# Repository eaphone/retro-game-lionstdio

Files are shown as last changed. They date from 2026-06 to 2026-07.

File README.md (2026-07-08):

# retro-game-lionstdio
a retro games console 

# Brief introduction:
## firmware based on [retro-go](https://github.com/eaphone/retro-go) integrated gba, dos simulator. add wired coplay, video player.
GBA, [Dos simulator](assets/dos-effect.gif) and video player.<br>
 
| win95 runing on esp32 | LEGEND runing on esp32s3 | video player |
| ---- | ---- | ---- |
|  |  | Videoplayer |

## hw use ili9342 drive 2.4 inch half transparent tft display, powered by esp32s3/p4
display without backlight, under sunshine effect \


# 3d print case without screw
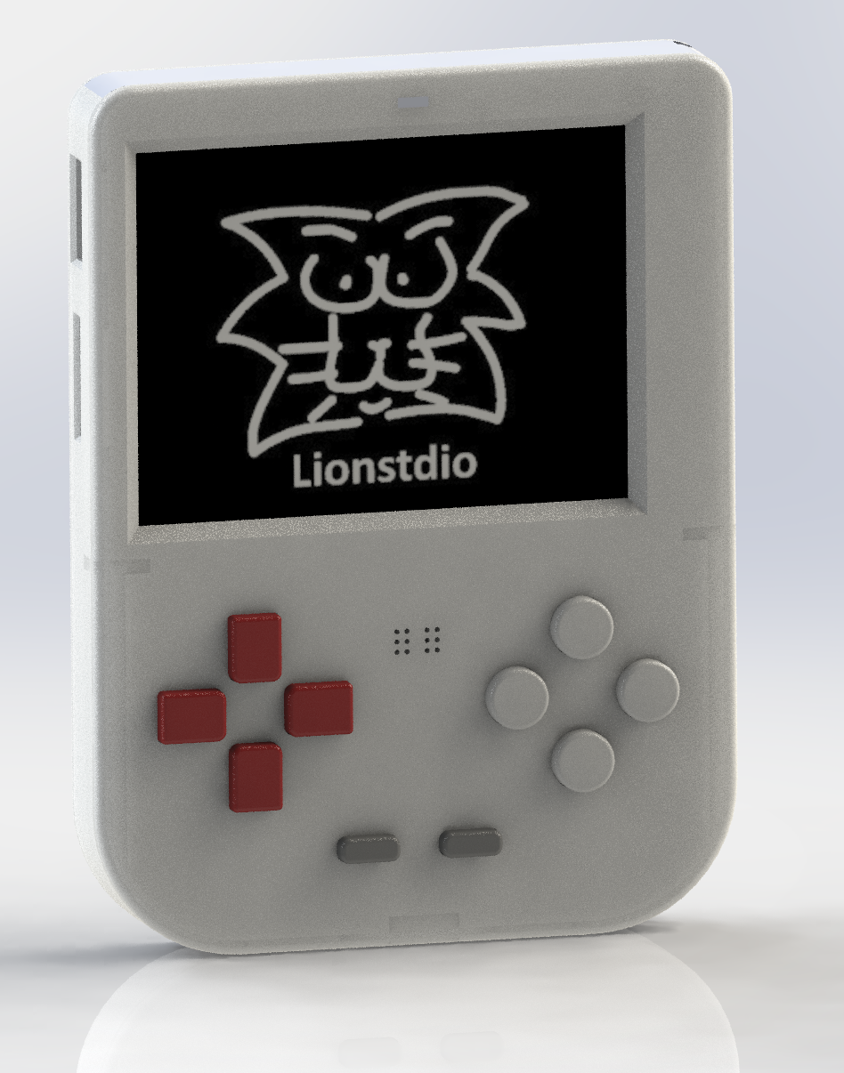
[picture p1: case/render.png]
render view


# Notice:
- ec gudie refer to [PCB_EC](pcb/README.md#ec)
- manufacture and assemble gudie refer to [PCB_MANUFACTURE](pcb/README.md#manufacture) [3D_PRINT_MANUFACTURE](case/README.md#manufacture) [ASSEMBLING](case/README.md#assemble)
- firmware flash and develop gudie refer to [FLASHING](pcb/README.md#flashing) [BUILDING](pcb/README.md#building)

# Final product:
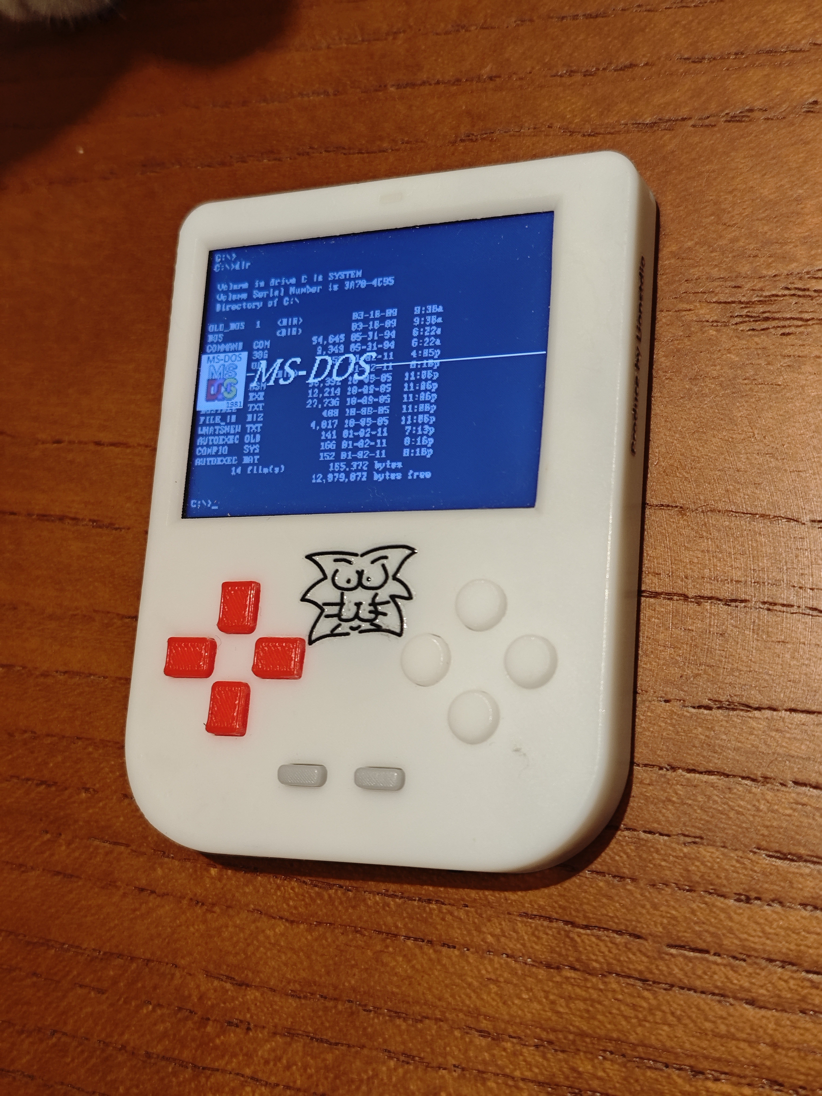
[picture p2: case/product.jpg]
product view


# Acknowledgements
this work is based on below awesome open source projects
- The retro-go is forked of the [retro-go](https://github.com/ducalex/retro-go) by ducalex and many others.
- The dos simulator is forked of the [tiny386](https://github.com/hchunhui/tiny386) by hchunhui.
- pcb desgin referred [虾哥小智游戏机](https://oshwhub.com/wdmomo/xiaozhi201) by wdmomo

# License
Everything in this project is licensed under the [GPLv2 license](COPYING)

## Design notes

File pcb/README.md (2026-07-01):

# Table of contents
- [Eletronic component](#ec)
- [Manufacture](#manufacture)
- [Building](#building)
- [Flashing](#flashing)

# Eletronic component
- main ecs are specified at BOMxx.xlsx for  s3/p4
- 10* round Snap dome 5mm (100g pressure is recommand)
- 1* 303759-750mah battery (30mm thin, 37*59mm size)

# Manufacture
JLC pcb service. parameter:\
1mm thiness, 2 layers

# Building
## environment
recommand Ubuntu + esp-idf 5.5.4

## build
source {path to esp-idf}/export.sh
### esp32s3
python rg_tool.py --target esp32-s3-devkit build-img 
### esp32p4
python rg_tool.py --target esp32-s3-devkit build-img --no-networking

# Flashing
- force device into download mode
1. power off the device
2. pull down the download pin (for esp32s3, press A; for esp32p4 press Up)
3. pwoer on the device
4. release the download pin

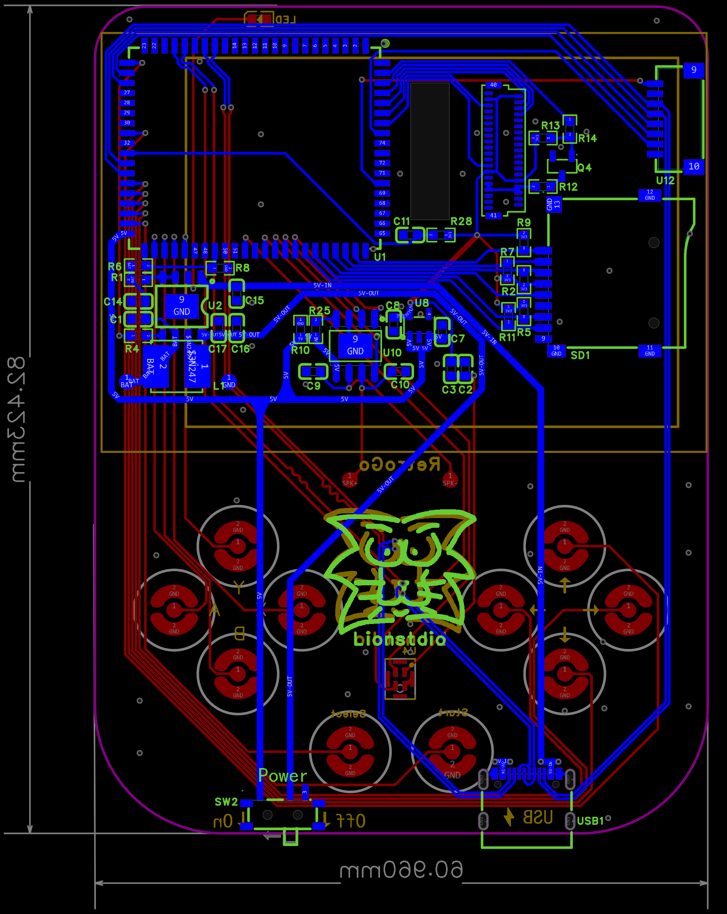
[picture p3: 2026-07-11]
pcb/esp32p4/PCB_P4_2026-07-11.png

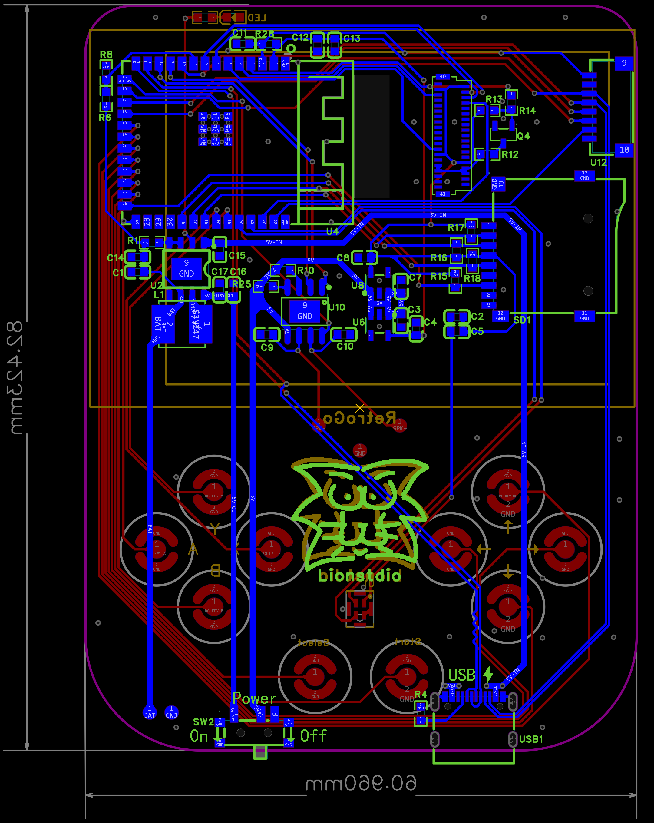
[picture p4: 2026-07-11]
pcb/esp32s3/PCB_S3_2026-07-11.png

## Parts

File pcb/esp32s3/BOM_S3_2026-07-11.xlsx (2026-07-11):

No. | Quantity | Comment | Designator | Footprint | Value | Manufacturer Part | Manufacturer | Supplier Part | Supplier
1 | 1 | TK024F3041_TK024F3089 | 2.4inch_IPS1 | TK024F3089
2 | 10 | smd button | A,B,Select,Start,X,Y,←,↑,→,↓ | 4MM锅仔片 |  | SKPMBHE010 | ALPS | C115350 | LCSC
3 | 4 | 22uF | C1,C14,C16,C17 | C0603 | 22uF | GRM188R61A226ME15D | muRata(村田) | C84419 | LCSC
4 | 1 | 100nF | C2 | C0603 | 100nF | CC0603KRX7R0BB104 | YAGEO(国巨) | C113803 | LCSC
5 | 5 | 1uF | C3,C4,C5,C7,C8 | C0603 | 1uF | CC0603KRX7R9BB105 | YAGEO(国巨) | C559769 | LCSC
6 | 2 | 220pF | C9,C10 | C0603 | 220pF | CL10C221JB8NNNC | SAMSUNG(三星) | C27675 | LCSC
7 | 2 | 100nF | C11,C12 | C0603 | 100nF | CC0603KRX7R9BB104 | YAGEO(国巨) | C14663 | LCSC
8 | 2 | 10uF | C13,C15 | C0603 | 10uF | GRM188R61E106KA73D | muRata(村田) | C344022 | LCSC
9 | 1 | 2.2uH | L1 | IND-SMD_L5.0-W5.0_LVS505040 | 2.2uH | LVS505020-2R2M-N | Chilisin(奇力新) | C142122 | LCSC
10 | 1 | BZ-C0603-S3-E1 | LED | LED0603-FD_BLUE |  | BZ-C0603-S3-E1 | baizou(百洲) | C2833062 | LCSC
11 | 1 | S8050 | Q4 | SOT-23-3_L2.9-W1.3-P1.90-LS2.3-BR |  | S8050 | R+O(宏嘉诚) | C20069125 | LCSC
12 | 2 | 1kΩ | R1,R14 | R0603 | 1kΩ | RC0603FR-071KL | YAGEO(国巨) | C22548 | LCSC
13 | 2 | 5.1kΩ | R3,R4 | R0603 | 5.1kΩ | 0603WAF5101T5E | UNI-ROYAL(厚声) | C23186 | LCSC
14 | 2 | 100kΩ | R6,R8 | R0603 | 100kΩ | RT0603BRD07100KL | YAGEO(国巨) | C122538 | LCSC
15 | 1 | 0Ω | R10 | R0603 | 0Ω | RC0603FR-070RL | YAGEO(国巨) | C100044 | LCSC
16 | 1 | 10Ω | R12 | R0603 | 10Ω | 0603WAJ0100T5E | UNI-ROYAL(厚声) | C25202 | LCSC
17 | 6 | 10kΩ | R13,R15,R16,R17,R18,R28 | R0603 | 10kΩ | 0603WAF1002T5E | UNI-ROYAL(厚声) | C25804 | LCSC
18 | 1 | 1MΩ | R25 | R0603 | 1MΩ | 0603WAF1004T5E | UNI-ROYAL(厚声) | C22935 | LCSC
19 | 1 | TF-CARD H1.8 SY | SD1 | TF-CARD-SMD_MT102010052 |  | TF-CARD H1.8 SY | SHOU HAN(首韩) | C7529391 | LCSC
20 | 1 | MK-12C02-G025 | SW2 | SW-SMD_MK-12C02-G025 |  | MK-12C02-G025 | G-Switch(品赞) | C778186 | LCSC
21 | 1 | IMP34DT05TR | U1 | HCLGA-5_L4.0-W3.0 |  | IMP34DT05TR | ST(意法半导体) | C2969844 | LCSC
22 | 1 | IP5306 | U2 | ESOP-8_L4.9-W3.9-P1.27-LS6.0-BL-EP |  | IP5306 | INJOINIC(英集芯) | C181692 | LCSC
23 | 1 | ESP32-S3-WROOM-1-N16R8 | U4 | WIRELM-SMD_ESP32-S3-WROOM-1 |  | ESP32-S3-WROOM-1-N16R8 | ESPRESSIF(乐鑫) | C2913202 | LCSC
24 | 2 | ME6211C33M5G-N | U6,U8 | SOT-23-5_L3.0-W1.7-P0.95-LS2.8-BL |  | ME6211C33M5G-N | MICRONE(南京微盟) | C82942 | LCSC
25 | 1 | HT517 | U10 | ESOP-8_L4.9-W3.9-P1.27-LS6.0-BL-EP-1
26 | 1 | SM08B-SRSS-TB(LF)(SN) | U12 | CONN-TH_SM08B-SRSS-TB-LF-SN |  | SM08B-SRSS-TB(LF)(SN) | JST | C160407 | LCSC
27 | 1 | TYPE-C16PIN | USB1 | USB-C-SMD_TYPE-C16PIN |  | TYPE-C16PIN | SHOU HAN(首韩) | C393939 | LCSC

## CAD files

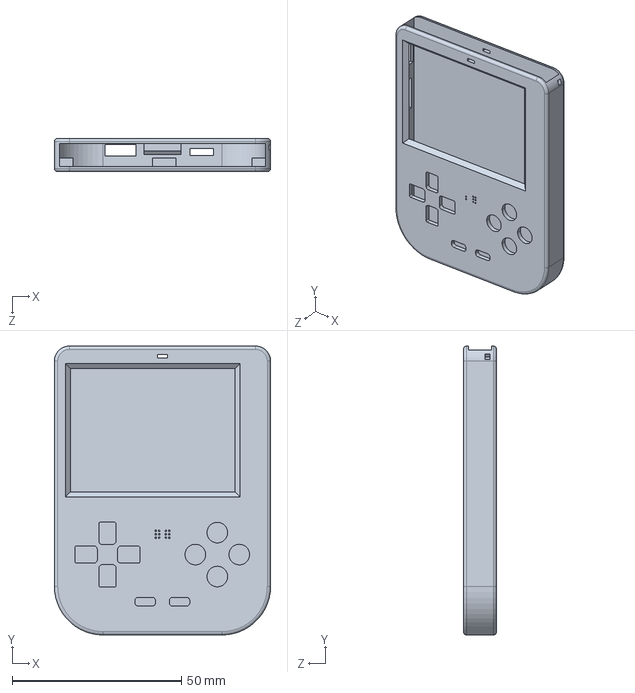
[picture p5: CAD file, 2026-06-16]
case/body-ver9.STEP
64.0 x 85.5 x 9.85 mm

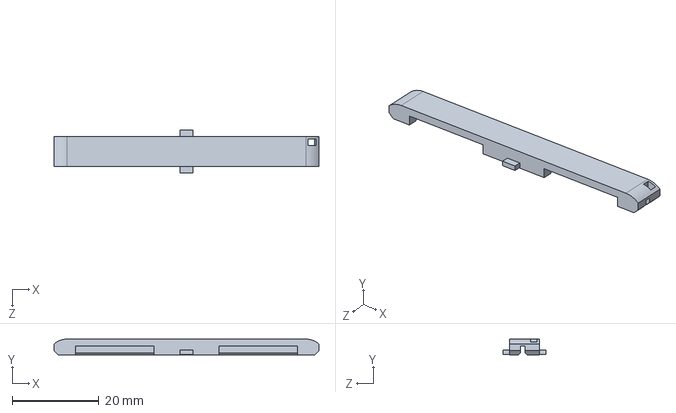
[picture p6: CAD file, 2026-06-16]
case/body-cover-ver9.STEP
61.0 x 3.65 x 9.85 mm

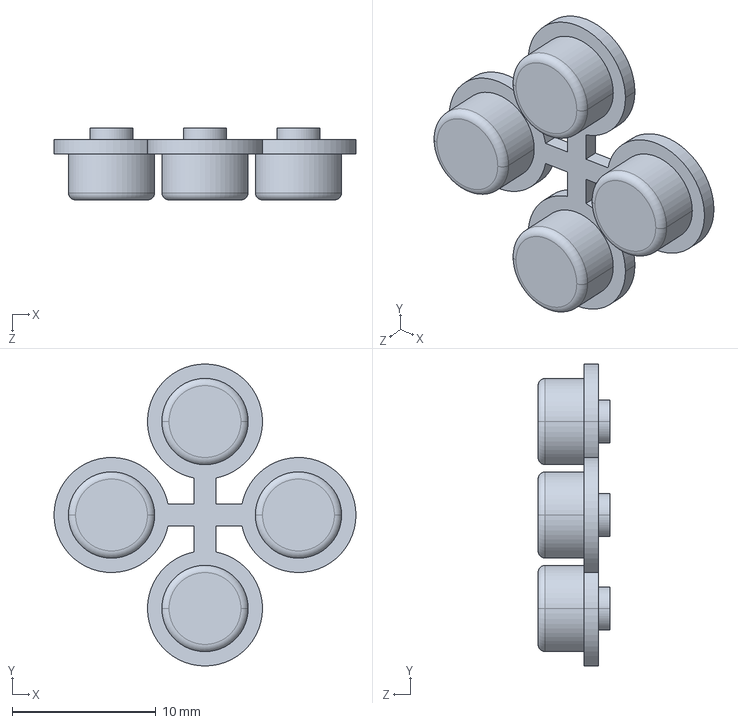
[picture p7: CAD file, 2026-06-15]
case/action-ver9.STEP
21.0 x 21.0 x 5.00 mm

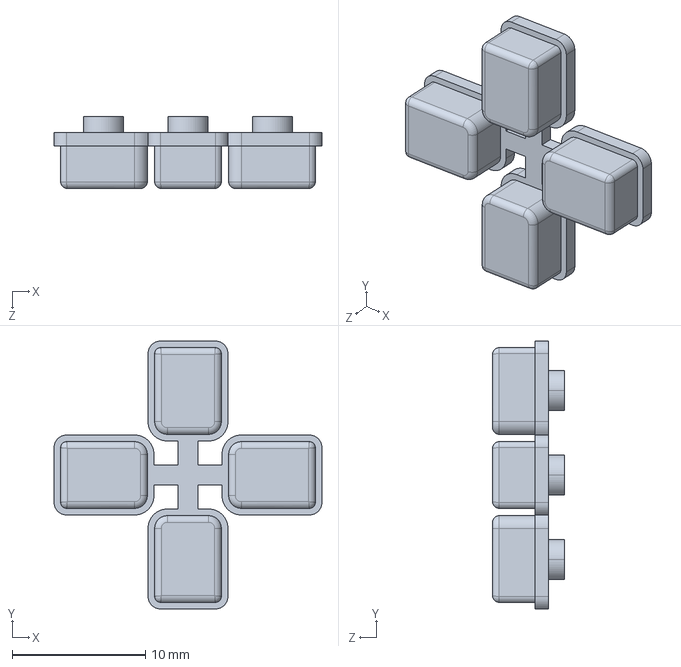
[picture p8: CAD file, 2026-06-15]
case/arrow-ver9.STEP
20.1 x 20.1 x 5.40 mm

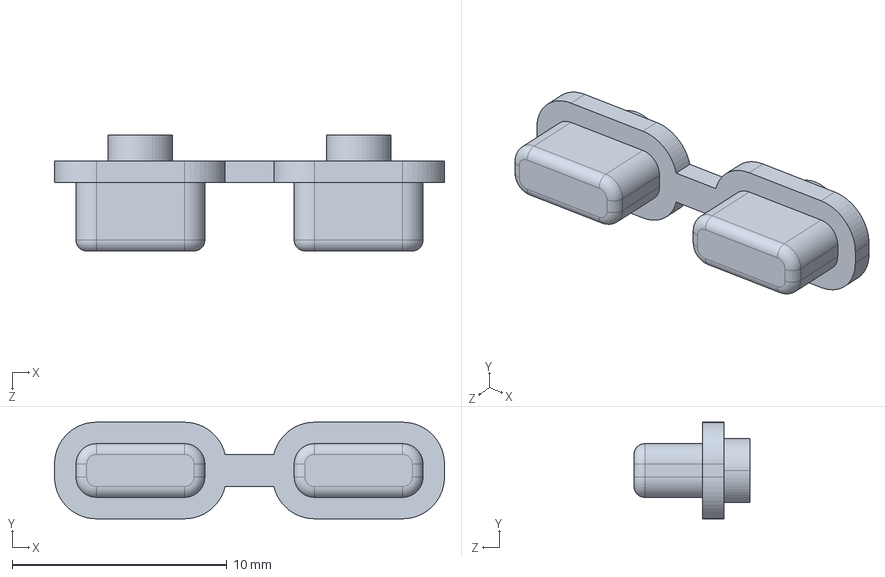
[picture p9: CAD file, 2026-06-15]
case/system-ver9.STEP
18.2 x 4.50 x 5.40 mm

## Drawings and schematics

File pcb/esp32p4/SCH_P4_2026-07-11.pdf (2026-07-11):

# ESP32-P4 32MB PSRAM 16MB FLASH

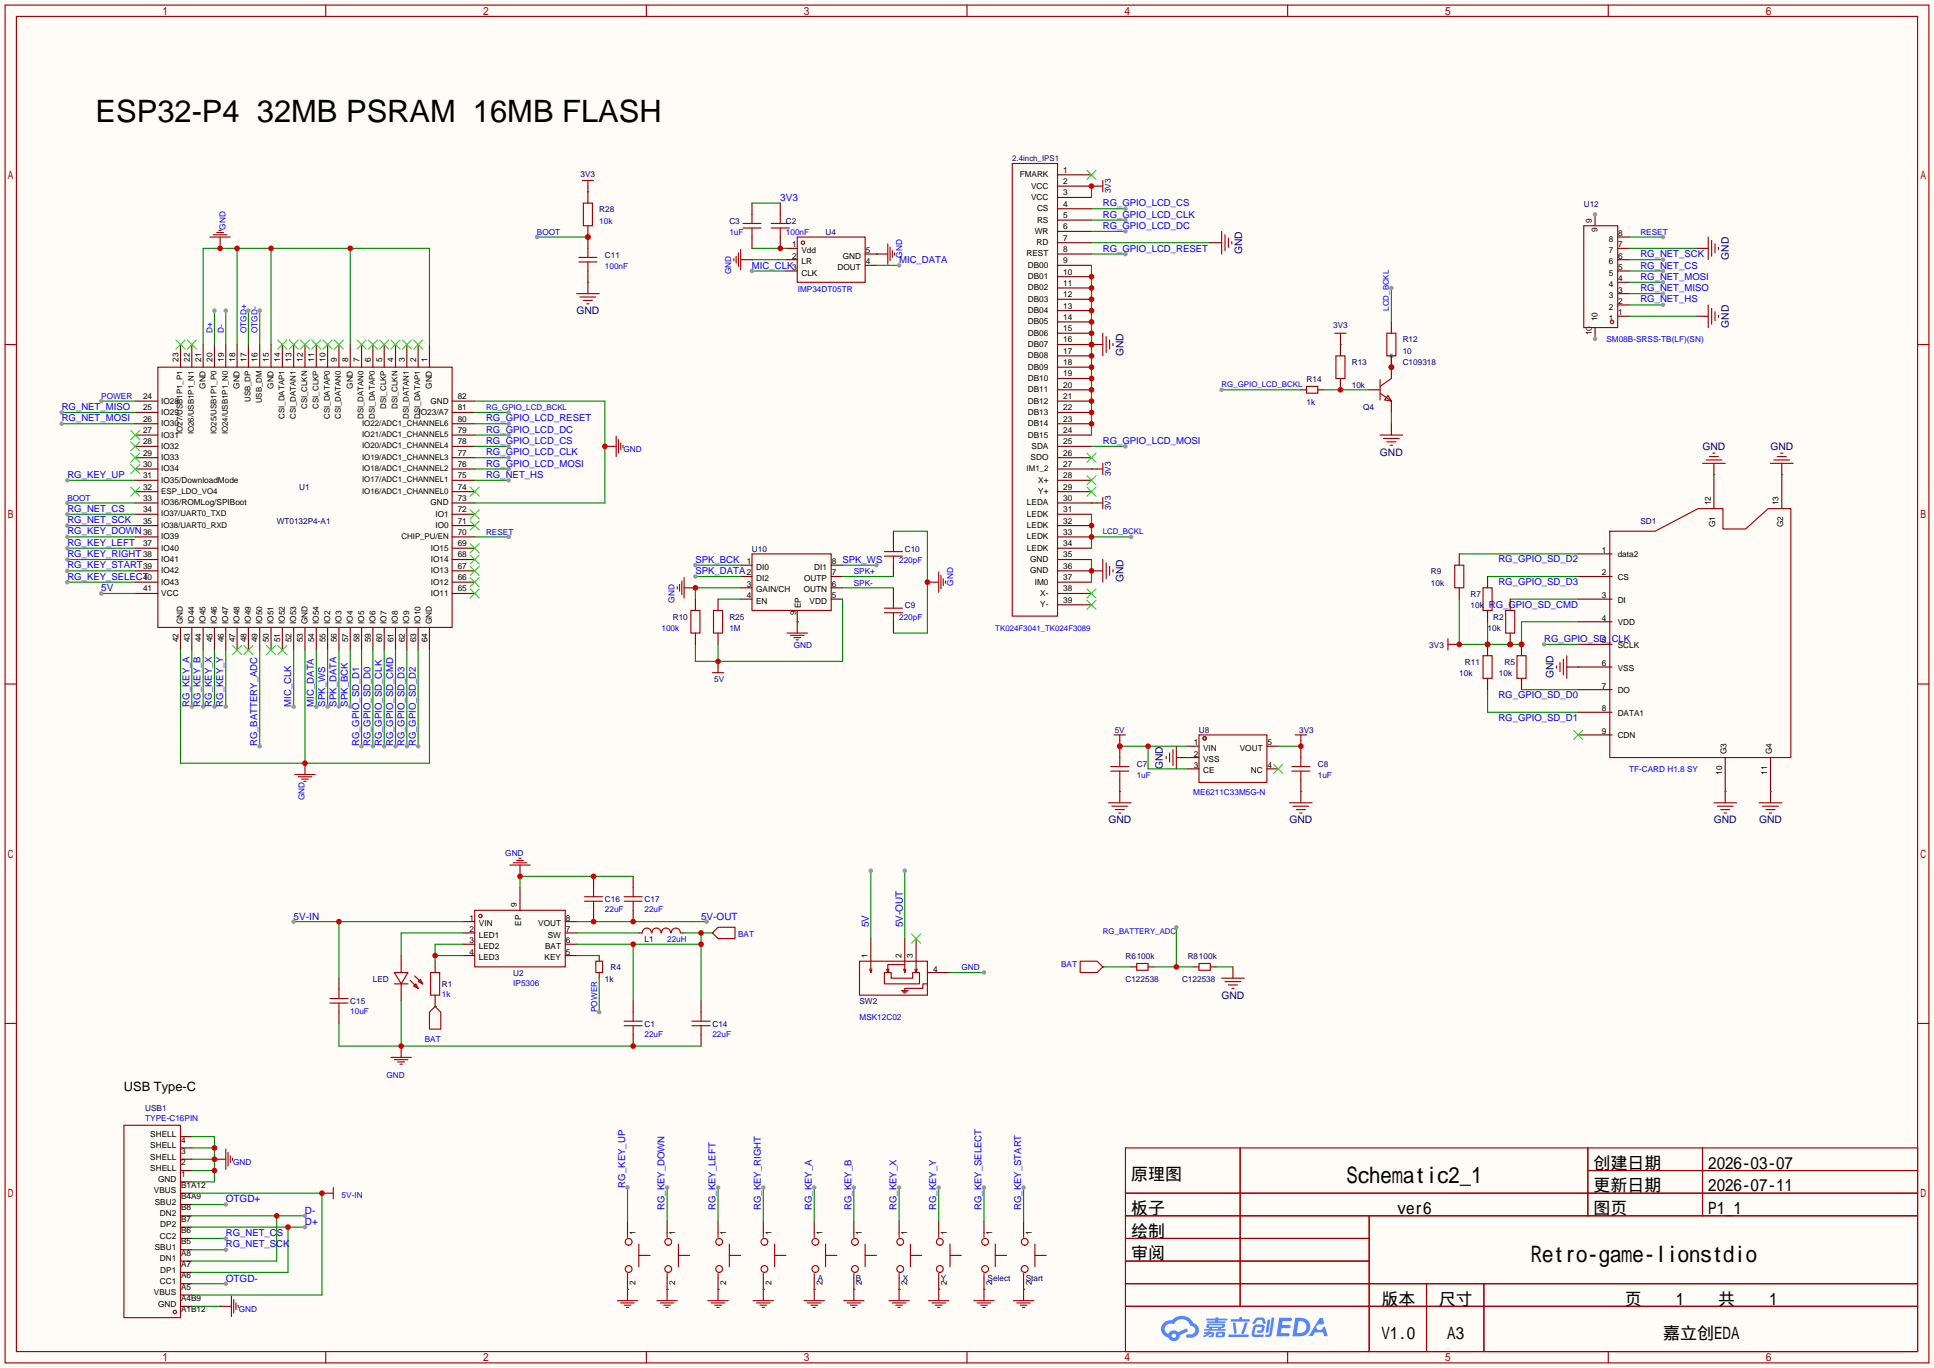
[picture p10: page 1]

SM08B-SRSS-TB(LF)(SN)

原理图 | Schematic2_1 | 创建日期 | 2026-03-07

更新日期 | 2026-07-11

板子 | ver6 | 图页 | P1_1
绘制 | | Retro-game-lionstdio
审阅

V1.0 | A3 | 嘉立创EDA

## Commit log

2026-06-15 add case
    [action-ver9.STEP, arrow-ver9.STEP, body-cover-ver9.STEP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]
2026-06-16 update model file
    [body-cover-ver9.STEP, body-ver9.STEP]
2026-07-11 update pc for net coplay
    [BOM_P4_2026-07-11.xlsx, BOM_S3_2026-07-11.xlsx, BOM_ver6_PCB5_1_2026-06-15.xlsx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]
